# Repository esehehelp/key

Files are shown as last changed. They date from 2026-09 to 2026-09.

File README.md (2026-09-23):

# CH32X035 12キー USB キーパッド

`key.kicad_sch` の 4 行 × 3 列スイッチを読み取り、USB **HID Boot Keyboard** として入力するファームウェアです。CDC シリアルも複合デバイスのまま残し、参照実装と同じ 1200 bps touch → BootROM 書き込みを使用します。スケッチは `firmware/keypad/keypad.ino`、ボードパッケージは `hardware/key/ch32x035f7p6/` です。

## 配線とキー

| | col1 PA0 | col2 PA1 | col3 PA2 |
|---|---|---|---|
| row1 PA3 | SW1: 0 | SW5: 1 | SW9: 2 |
| row2 PA4 | SW2: 3 | SW6: 4 | SW10: 5 |
| row3 PA5 | SW3: 6 | SW7: 7 | SW11: 8 |
| row4 PA6 | SW4: 9 | SW8: A | SW12: B |

列は順番に LOW 駆動し、非選択列は高インピーダンス、行はプルアップ入力です。ダイオードは行側がアノード・列側がカソード。約 5 ms のデバウンス、最大 6 キー同時押し、8 byte Boot Keyboard レポートを使用します。0–9 は NumLock に依存しない通常の数字キー、A/B は英字キーです（大文字になるかはホストの Shift/Caps Lock 次第）。配列 `keys` を変更すれば HID Usage を変更できます。PC3 は操作しません。回路図では LED のカソードが VDD 側で逆方向のため、ソフトウェアだけでは点灯できません。PC18/19 の SWD、PC14–17 の USB には触れません。SW40 は USB D+ 側の回路、SW41 はリセットであり、キー配列には含みません。

## Arduino IDE / CLI

このリポジトリのボードパッケージは [ch32x035f7p6-micro-devboard](../ch32x035f7p6-micro-devboard) の Arduino コア・起動処理・GPIO・USB CDC・アップロードツールをコピーしたものです。**HID 複合デバイス対応だけ** `cores/arduino/ch32x_cdc.c` を拡張しています。通常の Micro Devboard ボードではなく、必ず **CH32X035F7P6 Keypad** を選択してください (FQBN `key:ch32x035f7p6:ch32x035f7p6`)。スケッチは追加の `.h` に依存せず、HID 送信関数を `.ino` 内で宣言します。ただし実装はこのボードコアにあるため、未導入ならこのリポジトリのボードパッケージをインストールしてください。USB ID は参照 CDC 専用版の 1A86:FE0C と区別して **1A86:FE0D** です（試作用 ID。製品化時は正規の VID/PID に変更すること）。

### Windows

1. このリポジトリをダウンロードして**展開**し、`setup.bat` をダブルクリックします。これだけでボード・GCC・wchisp・DLL をインストールします。既存ツールがあれば再利用し、不足分だけダウンロードします。参照ボードの古い `install.ps1` や削除済みブランチを使う必要はありません。`.ps1` だけダブルクリックしても実行されないので `setup.bat` を使用してください。
2. 完了/失敗の表示を確認します。スケッチブックが特殊な場所ならコマンドプロンプトから `setup.bat -Sketchbook D:\Arduino` を実行できます。Arduino IDE を再起動します。**初めて** WCH USB ISP で書き込む Windows マシンでは、別途 WCH の署名済み ISP ドライバが必要です（参照ボードの手順を参照）。すでに参照ボードを書き込めているなら不要です。
3. IDE でボード **CH32X035F7P6 Keypad** と CDC ポートを選択し、`firmware/keypad/keypad.ino` を開いて Verify / Upload します。CLI なら以下のコマンドを使えます。

### Linux

参照リポジトリの PlatformIO CH32 用 toolchain (`~/.platformio/packages/toolchain-riscv/bin`) と `wchisp` を用意し、`./install.sh` を実行します。インストール先は既定で `~/Arduino/hardware/key/ch32x035f7p6` です。別のスケッチブック・ツールチェインなら `./install.sh /path/to/sketchbook /path/to/toolchain/bin` と指定します。Python 3 と `wchisp` を PATH に配置してください。

```sh
arduino-cli compile --fqbn key:ch32x035f7p6:ch32x035f7p6 firmware/keypad
arduino-cli upload -p /dev/ttyACM0 --fqbn key:ch32x035f7p6:ch32x035f7p6 firmware/keypad
```

初回（CDC ファームウェア未書き込み）や BootROM 起動済みの場合は `-p none` でアップロードするか、参照ボードと同じ wch-link / WCH ISP の手順で初回書き込みを行ってください。実機の Arduino CLI 書き込み・検証と USB 複合デバイス列挙（cdc_acm / usbhid）を確認済みです。実キーの押下動作は未確認です。

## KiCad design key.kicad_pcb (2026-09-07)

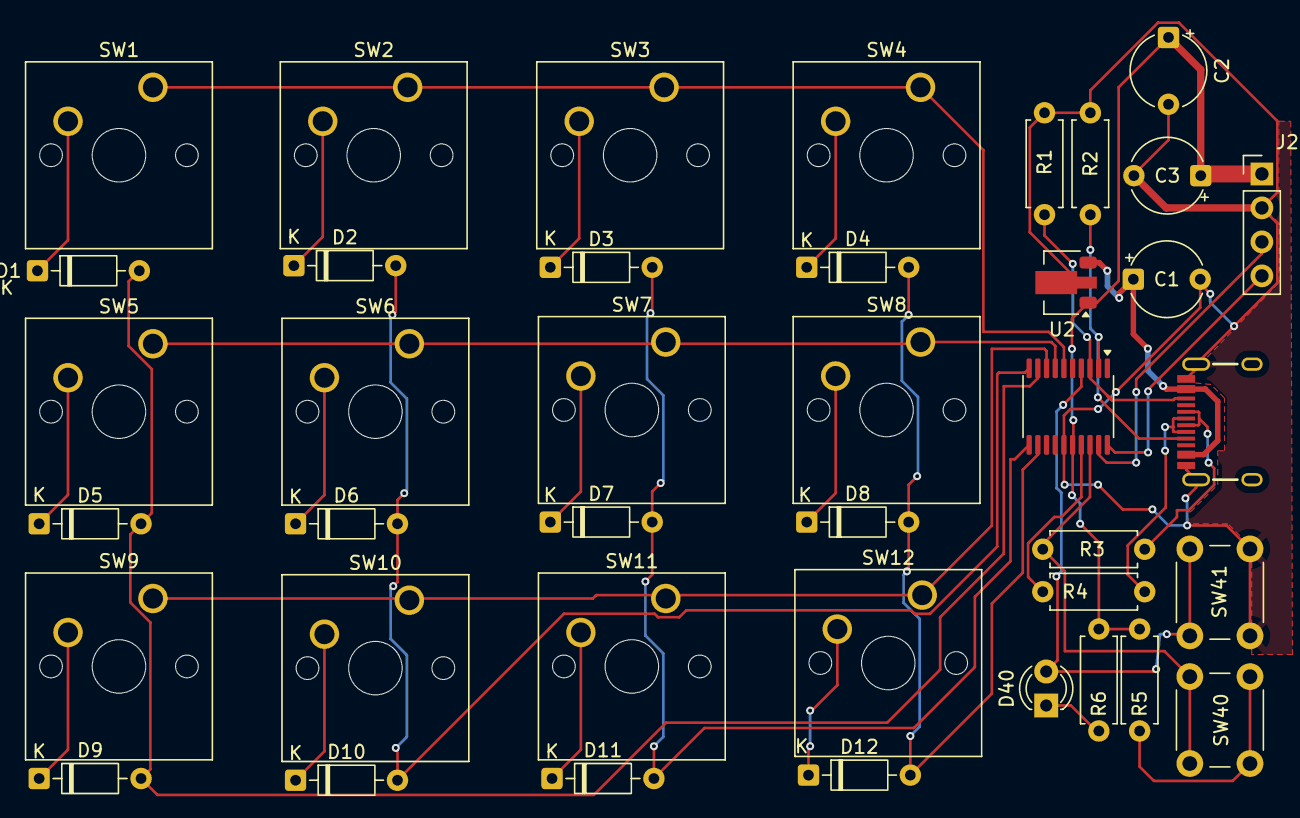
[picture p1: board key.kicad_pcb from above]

Board: 2 copper layers, 40 parts (0 on the bottom side), 33 nets.

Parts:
C1, C2: 10u/35V; CP_Radial_Tantal_D5.5mm_P5.00mm
C3: 0.1u/50V; CP_Radial_Tantal_D5.5mm_P5.00mm
D1, D2, D3, D4, D5, D6, D7, D8, D9, D10, D11, D12: 1N4148; D_DO-35_SOD27_P7.62mm_Horizontal
D40: Red_LED; LED_D3.0mm
J1: USB_C_Receptacle; USB-C_16-HandSolder
J2: SWDIO; PinHeader_1x04_P2.54mm_Vertical
R1, R2, R5: 5k1; R_Axial_DIN0207_L6.3mm_D2.5mm_P7.62mm_Horizontal
R3, R4: 22; R_Axial_DIN0207_L6.3mm_D2.5mm_P7.62mm_Horizontal
R6: 1k; R_Axial_DIN0207_L6.3mm_D2.5mm_P7.62mm_Horizontal
SW1, SW2, SW3, SW4, SW5, SW6, SW7, SW8, SW9, SW10, SW11, SW12: SW_MEC_5G; SW_Cherry_MX_1.00u_PCB
SW40, SW41: EVPAWCD40; SW_PUSH_6mm
U1: CH32X035F7P6; TSSOP-20_4.4x6.5mm_P0.65mm
U2: NJM78L33SU3; SOT-89-3

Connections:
CC1: J1.A5 (CC1), R2.1, U1.2 (CC1/PC14)
CC2: J1.B5 (CC2), R1.1, U1.3 (CC2/PC15)
D+: R3.1, SW40.1, U1.18 (UDP/PC17)
D-: R4.1, U1.17 (UDM/PC16)
GND: C1.2, C2.2, C3.2, J1.GND, J1.S (SHIELD), J2.2, R1.2, R2.2, SW41.2, U1.15 (GND), U2.2 (GND)
unnamed: D1.1 (K), SW1.2 (A)
unnamed: D2.1 (K), SW2.2 (A)
unnamed: D3.1 (K), SW3.2 (A)
unnamed: D4.1 (K), SW4.2 (A)
unnamed: D5.1 (K), SW5.2 (A)
unnamed: D6.1 (K), SW6.2 (A)
unnamed: D7.1 (K), SW7.2 (A)
unnamed: D8.1 (K), SW8.2 (A)
unnamed: D9.1 (K), SW9.2 (A)
unnamed: D10.1 (K), SW10.2 (A)
unnamed: D11.1 (K), SW11.2 (A)
unnamed: D12.1 (K), SW12.2 (A)
unnamed: D40.1 (K), R6.1
unnamed: J1.A6 (D+), J1.B6 (D+), R3.2
unnamed: J1.A7 (D-), J1.B7 (D-), R4.2
unnamed: R5.1, SW40.2
PC3: D40.2 (A), SW41.1, U1.4 (NRST/PC3)
PC18: J2.3, U1.19 (SWDIO/PC18)
PC19: J2.4, U1.20 (SWCLK/PC19)
VBUS: C1.1, J1.VBUS, U2.3 (IN)
VDD: C2.1, C3.1, J2.1, R5.2, R6.2, U1.16 (VDD), U2.1 (OUT)
col1: SW1.1 (A), SW2.1 (A), SW3.1 (A), SW4.1 (A), U1.6 (PA0)
col2: SW5.1 (A), SW6.1 (A), SW7.1 (A), SW8.1 (A), U1.7 (PA1)
col3: SW9.1 (A), SW10.1 (A), SW11.1 (A), SW12.1 (A), U1.8 (PA2)
row1: D1.2 (A), D5.2 (A), D9.2 (A), U1.9 (PA3)
row2: D2.2 (A), D6.2 (A), D10.2 (A), U1.10 (PA4)
row3: D3.2 (A), D7.2 (A), D11.2 (A), U1.11 (PA5)
row4: D4.2 (A), D8.2 (A), D12.2 (A), U1.12 (PA6)

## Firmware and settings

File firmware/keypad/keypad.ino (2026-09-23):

#include <Arduino.h>
#include <string.h>

// Implemented by this board core's CDC + HID composite USB driver.
extern "C" int ch32x_hid_send(const uint8_t report[8]);

// Schematic: SW1..4=col1 PA0, SW5..8=col2 PA1, SW9..12=col3 PA2.
// D1/D5/D9 anodes=row1 PA3; row2 PA4; row3 PA5; row4 PA6.
// Drive one column LOW at a time; all other columns are high impedance.
// Diode current flows from pulled-up row (anode) to selected column (cathode).
static const uint8_t cols[3] = {PA0, PA1, PA2};
static const uint8_t rows[4] = {PA3, PA4, PA5, PA6};
// USB HID keyboard usages: 0..9, A, B (top row digits, independent of NumLock).
static const uint8_t keys[4][3] = {
  {0x27, 0x1E, 0x1F}, // 0 1 2
  {0x20, 0x21, 0x22}, // 3 4 5
  {0x23, 0x24, 0x25}, // 6 7 8
  {0x26, 0x04, 0x05}  // 9 A B
};

static uint16_t stable, previous;
static uint8_t count[12];
static uint8_t last_sent[8];
static unsigned long last_scan, last_report;

static uint16_t scan_matrix() {
  uint16_t bits = 0;
  for (uint8_t c = 0; c < 3; ++c) {
    digitalWrite(cols[c], LOW);
    pinMode(cols[c], OUTPUT);
    delayMicroseconds(5);
    for (uint8_t r = 0; r < 4; ++r)
      if (digitalRead(rows[r]) == LOW) bits |= (uint16_t)1 << (r * 3 + c);
    pinMode(cols[c], INPUT); // never drive another column against this one
  }
  return bits;
}

void setup() {
  for (uint8_t r = 0; r < 4; ++r) pinMode(rows[r], INPUT_PULLUP);
  for (uint8_t c = 0; c < 3; ++c) pinMode(cols[c], INPUT);
}

void loop() {
  unsigned long now = millis();
  if ((unsigned long)(now - last_scan) < 1) return;
  last_scan = now;
  uint16_t raw = scan_matrix();
  for (uint8_t i = 0; i < 12; ++i) {
    uint16_t mask = (uint16_t)1 << i;
    if ((raw & mask) == (previous & mask)) {
      if (count[i] < 5) ++count[i];
    } else count[i] = 0;
    if (count[i] == 5) {
      if (raw & mask) stable |= mask;
      else stable &= ~mask;
    }
  }
  previous = raw;

  uint8_t report[8] = {0};
  uint8_t n = 0;
  for (uint8_t i = 0; i < 12; ++i)
    if ((stable & ((uint16_t)1 << i)) && n < 6)
      report[2 + n++] = keys[i / 3][i % 3];
  // Refresh on reconnection / lost transfers, including an all-released report.
  if (memcmp(report, last_sent, 8) || (unsigned long)(now - last_report) >= 250) {
    if (ch32x_hid_send(report)) {
      memcpy(last_sent, report, 8);
      last_report = now;
    }
  }
}

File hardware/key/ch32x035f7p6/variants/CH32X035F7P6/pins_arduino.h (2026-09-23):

/*
 * pins_arduino.h — Pin mapping for CH32X035F7P6 Micro Devboard.
 *
 * CH32X035F7P6 (TSSOP20) available GPIO:
 *   PA0-PA7, PB1, PB12, PC1, PC3, PC18(SWDIO), PC19(SWCLK)
 *   PC14/15/16/17 reserved for USB CDC (CC1, CC2, D-, D+)
 *
 * SPDX-License-Identifier: MIT
 */
#ifndef pins_arduino_h
#define pins_arduino_h

#define NUM_DIGITAL_PINS    14
#define NUM_ANALOG_INPUTS   8

/* Stable Arduino numbers. The board silk uses MCU port names, so sketches can
 * use either PA0/PC1/etc. or D0/D10/etc. without guessing numeric values. */
#define PIN_PA0             0
#define PIN_PA1             1
#define PIN_PA2             2
#define PIN_PA3             3
#define PIN_PA4             4
#define PIN_PA5             5
#define PIN_PA6             6
#define PIN_PA7             7
#define PIN_PB1             8
#define PIN_PB12            9
#define PIN_PC1             10
#define PIN_PC3             11
#define PIN_PC18            12
#define PIN_PC19            13

#define PA0                 PIN_PA0
#define PA1                 PIN_PA1
#define PA2                 PIN_PA2
#define PA3                 PIN_PA3
#define PA4                 PIN_PA4
#define PA5                 PIN_PA5
#define PA6                 PIN_PA6
#define PA7                 PIN_PA7
#define PB1                 PIN_PB1
#define PB12                PIN_PB12
#define PC1                 PIN_PC1
#define PC3                 PIN_PC3
#define PC18                PIN_PC18
#define PC19                PIN_PC19

#define D0                  PIN_PA0
#define D1                  PIN_PA1
#define D2                  PIN_PA2
#define D3                  PIN_PA3
#define D4                  PIN_PA4
#define D5                  PIN_PA5
#define D6                  PIN_PA6
#define D7                  PIN_PA7
#define D8                  PIN_PB1
#define D9                  PIN_PB12
#define D10                 PIN_PC1
#define D11                 PIN_PC3
#define D12                 PIN_PC18
#define D13                 PIN_PC19

/* Board functions. PC3 is shared by the LED, RESET switch, and the MCU's
 * NRST/PC3 pad. PC18/PC19 remain usable as GPIO but doing so occupies SWD. */
#define LED_BUILTIN         PIN_PC3
#define PIN_LED             PIN_PC3
#define PIN_SWDIO           PIN_PC18
#define PIN_SWCLK           PIN_PC19

/* Peripheral-capable pins exposed by this package. These names describe the
 * hardware routing; SPI/UART classes are not implemented in this minimal core. */
#define PIN_SPI_SS          PIN_PA4
#define PIN_SPI_SCK         PIN_PA5
#define PIN_SPI_MISO        PIN_PA6
#define PIN_SPI_MOSI        PIN_PA7
#define PIN_HARDWARE_SERIAL_TX PIN_PA2
#define PIN_HARDWARE_SERIAL_RX PIN_PA3

/*
 * Arduino pin  ->  GPIO
 *   D0  = PA0       (A0)
 *   D1  = PA1       (A1)
 *   D2  = PA2       (A2)
 *   D3  = PA3       (A3)
 *   D4  = PA4       (A4)
 *   D5  = PA5       (A5)
 *   D6  = PA6       (A6)
 *   D7  = PA7       (A7)
 *   D8  = PB1
 *   D9  = PB12
 *   D10 = PC1
 *   D11 = PC3       (LED)
 *   D12 = PC18      (SWDIO — usable as GPIO)
 *   D13 = PC19      (SWCLK — usable as GPIO)
 */

/* Analog pin aliases */
#define A0  PIN_PA0
#define A1  PIN_PA1
#define A2  PIN_PA2
#define A3  PIN_PA3
#define A4  PIN_PA4
#define A5  PIN_PA5
#define A6  PIN_PA6
#define A7  PIN_PA7

#endif /* pins_arduino_h */

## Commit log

2026-09-23 Add Arduino USB HID keypad firmware for CH32X035
2026-09-23 Expose HID API through Arduino.h for IDE sketches
2026-09-23 Declare HID send API directly in Arduino sketch
2026-09-23 Find IDE sketchbook when installing Windows board package
2026-09-23 Document current reference installer branch for Windows
